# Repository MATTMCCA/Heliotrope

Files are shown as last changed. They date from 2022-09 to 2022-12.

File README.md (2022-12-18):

# Heliotrope

All hardware design was done with Altium, all 3D modeling (with the exception of available models) was done with Fusion360.

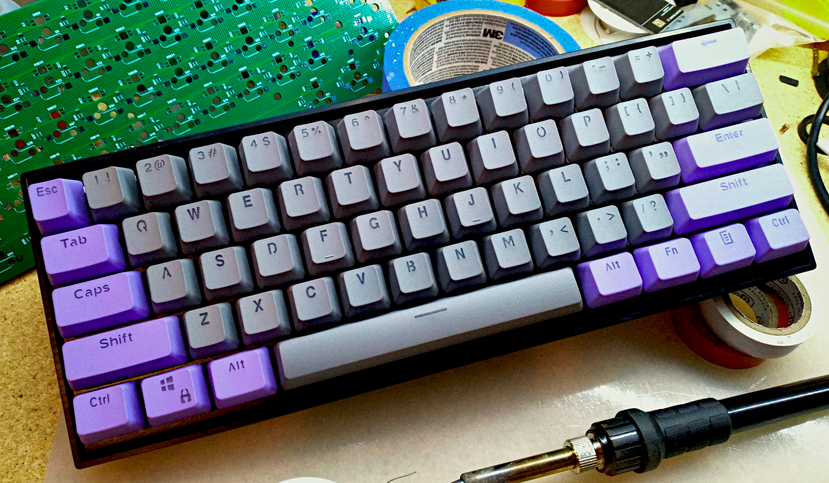
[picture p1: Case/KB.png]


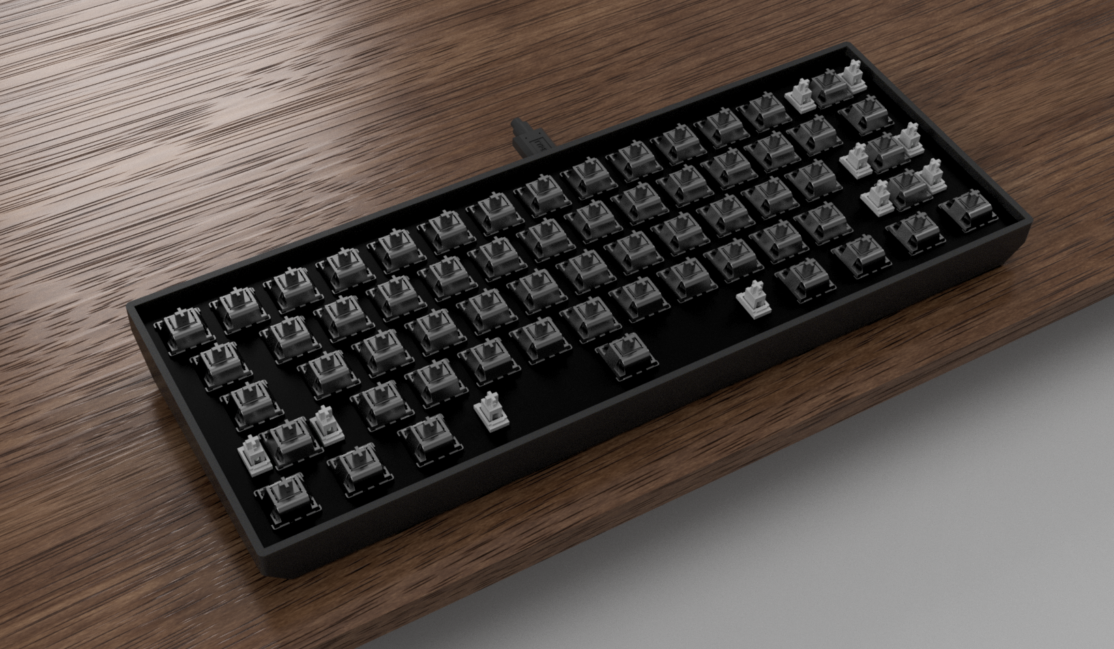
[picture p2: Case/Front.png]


MIT licensed keyboard.

"Buy Me A Coffee" (https://www.buymeacoffee.com/mccardlema3)

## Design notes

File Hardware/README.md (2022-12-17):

# View All Project Files Online

https://www.altium.com/viewer/

## Note:

Resistors R1, R2, R6, of the logic board should be changed, the **actual** current limits will be less than whats listed in the schematic.

The Keyswitch PCB still only has one via connecting VCC to all LED's. At extremely high current the via may fail. The circumference of the via is 24.7369mil, assuming 0.5oz copper plating, this should be able to handle 1.6A at a 30C rise from ambient (25C).

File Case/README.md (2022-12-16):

# Heliotrope

The Keyboard Case was milled out of ABS by [ProtoTool](https://prototool.com/). 

The KeyPlate was laser cut, formed and powered coated by [OshCut](https://www.oshcut.com/).

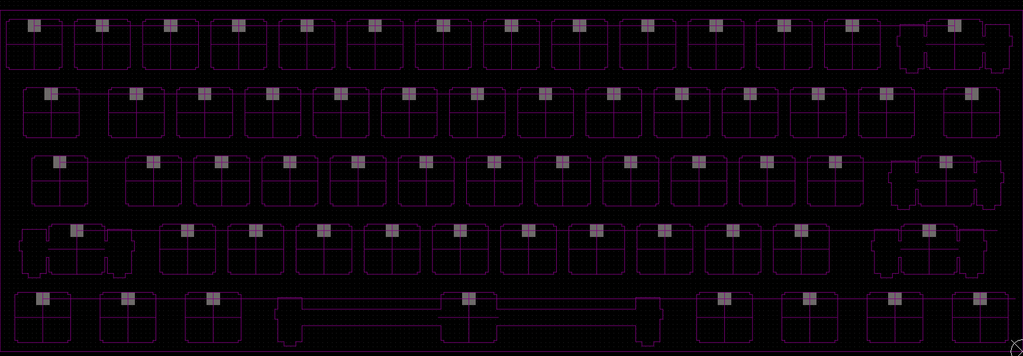
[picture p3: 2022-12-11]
Docs/src/LedPloter/ledPlot_ref_org.bmp

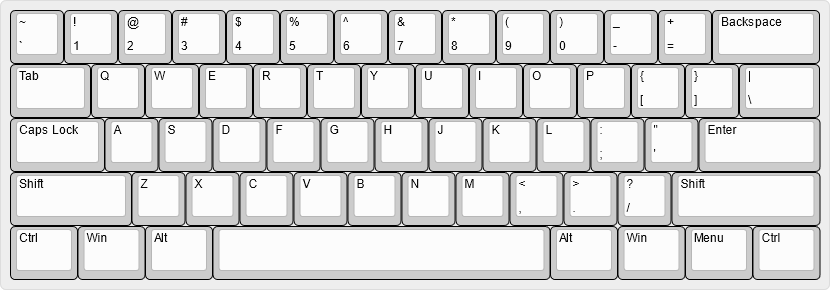
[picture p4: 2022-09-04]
Docs/src/Heliotrope_layout.png

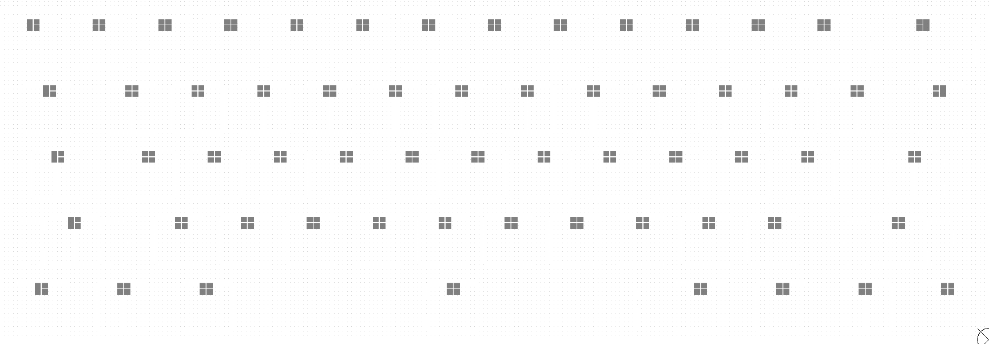
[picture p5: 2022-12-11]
Docs/src/LedPloter/ledPlot_ref.bmp

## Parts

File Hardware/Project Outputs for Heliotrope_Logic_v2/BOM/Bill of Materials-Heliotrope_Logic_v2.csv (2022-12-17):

Name | Description | Designator | Quantity | Manufacturer 1 | Manufacturer Part Number 1
53261-0271 | 1.25mm Pitch PicoBlade™ Header, Surface Mount, Right Angle, Lead-Free, 2 Circuits | P1 | 1 | Molex | 53261-0271
MIC803-26D4VC3-TR | 3-Pin Microprocessor Supervisor Circuit w/ Open-Drain Reset Output | U2 | 1 | Microchip | MIC803-26D4VC3-TR
0603L010YR | 15VDC 100mA | F1 | 1 | Littelfuse | 0603L010YR
TLV74033PDBVR | 300-mA low-dropout (LDO) regulator with foldback current limit 5-SOT-23 -40 to 125 | U3 | 1 | Texas Instruments | TLV74033PDBVR
BLM18AG601SN1D | 600 Ohms @ 100MHz 1 Ferrite Bead 0603 _1608 Metric_ 500mA 380mOhm | FL1 | 1 | Murata | BLM18AG601SN1D
CC0603JRX7R9BB104 | 0603 0.1 uF 50 V ±5 % Tolerance X7R SMT Multilayer Ceramic Capacitor | C2, C5, C6, C7, C8, C9, C10, C11, C12, C14 | 10 | Yageo | CC0603JRX7R9BB104
STM32F411CEU6 | ARM® Cortex®-M4 STM32 F4 Microcontroller IC 32-Bit 100MHz 512KB (512K x 8) FLASH 48-UFQFPN (7x7) | U1 | 1 | STMicroelectronics | STM32F411CEU6
CC0603KRX7R6BB225 | Cap Ceramic 2.2uF 10V X7R 10% SMD 0603 125C Paper T/R | C1 | 1 | Yageo | CC0603KRX7R6BB225
GRM21BR71A106KA73K | Cap Ceramic 10uF 10V X7R 10% Pad SMD 0805 125C T/R | C3, C4, C13 | 3 | Murata | GRM21BR71A106KA73K
USB4110-GF-A | Conn USB Type C RCP 16 POS 0.3mm/0.5mm Solder ST SMD 16 Terminal 1 Port T/R | J1 | 1
ECS-2520MV-080-CN-TR | ECS-2520MV Series 8MHz 2.5x2mm 3.6 V SMT HCMOS Multivolt? Crystal Oscillator | Y1 | 1 | ECS International | ECS-2520MV-080-CN-TR
RCLAMP0504FBTCT | ESD Suppressor TVS Quad Uni-Dir 30kV 6-Pin SC-70 T/R | CR1 | 1 | Semtech | RCLAMP0504FBTCT
68712014522 | Ffc / Fpc Board Connector, Zif, Surface Mount, Plug, 20, Bottom, 0.5 Mm Rohs Compliant: Yes | J2 | 1 | Wurth Electronics | 68712014522
AP22653AW6-7 | PRECISION ADJUSTABLE CURRENT-LIMITED POWER SWITCHES, -40 to 85°C pF, RoHS | U4 | 1 | Diodes | AP22653AW6-7
PTN5150AHXMP | PTN5150A Series 2.7 to 5.5 V CC Logic for USB Type-C Applications - XFQFN-12 | U5 | 1 | NXP Semiconductors | PTN5150AHXMP
RMCF0603JT1K00 | Res Thick Film 0603 1K Ohm 5% 1/10W ±200ppm/°C Molded SMD Paper T/R | R5 | 1 | Stackpole Electronics | RMCF0603JT1K00
RMCF0603JT10K0 | Res Thick Film 0603 10K Ohm 5% 1/10W ±100ppm/°C Molded SMD SMD Paper T/R | R4, R7 | 2 | Stackpole Electronics | RMCF0603JT10K0
RMCF0603FT33K0 | Res Thick Film 0603 33K Ohm 1% 0.1W(1/10W) ±100ppm/C Pad SMD Automotive T/R | R2 | 1 | Stackpole Electronics | RMCF0603FT33K0
RMCF0603FT62K0 | Res Thick Film 0603 62K Ohm 1% 1/10W ±100ppm/°C Molded SMD SMD Paper T/R | R1 | 1 | Stackpole Electronics | RMCF0603FT62K0
RMCF0603JT100K | Res Thick Film 0603 100K Ohm 5% 1/10W ±200ppm/°C Molded SMD Paper T/R | R3 | 1 | Stackpole Electronics | RMCF0603JT100K
RMCF0603FT102K | Res Thick Film 0603 102K Ohm 1% 1/10W ±100ppm/°C Molded SMD SMD Paper T/R | R6 | 1 | Stackpole Electronics | RMCF0603FT102K
PTS526SK15SMTR2LFS | Switch Tactile N.O. SPST Round Button Gull Wing 0.05A 12VDC 200000Cycles 2.55N SMD T/R | SW1 | 1 | ITT C&K | PTS526SK15SMTR2LFS

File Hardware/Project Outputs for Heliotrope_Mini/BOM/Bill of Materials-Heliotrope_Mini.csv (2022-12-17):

Name | Description | Designator | Quantity | Manufacturer 1 | Manufacturer Part Number 1
CC0603JRX7R9BB104 | 0603 0.1 uF 50 V ±5 % Tolerance X7R SMT Multilayer Ceramic Capacitor | C1, C2, C3, C4, C5, C6, C7, C8, C9, C10, C11, C12, C13, C14, C15, C16, C17, C18, C19, C20, C21, C22, C23, C24, C25, C26, C27, C28, C29, C30, C31, C32, C33, C34, C35, C36, C37, C38, C39, C40, C41, C42, C43, C44, C45, C46, C47, C48, C49, C50, C51, C52, C53, C54, C55, C56, C57, C58, C59, C60, C61 | 61 | Yageo | CC0603JRX7R9BB104
RB520S30T5G | RB520S30T5G - 30 V 200 mA Surface Mount Schottky Diode - SOD-523 | D1, D2, D3, D4, D5, D6, D7, D8, D9, D10, D11, D12, D13, D14, D15, D16, D17, D18, D19, D20, D21, D22, D23, D24, D25, D26, D27, D28, D29, D30, D31, D32, D33, D34, D35, D36, D37, D38, D39, D40, D41, D42, D43, D44, D45, D46, D47, D48, D49, D50, D51, D52, D53, D54, D55, D56, D57, D58, D59, D60, D61 | 61 | ON Semiconductor | RB520S30T5G
68712014522 | Ffc / Fpc Board Connector, Zif, Surface Mount, Plug, 20, Bottom, 0.5 Mm Rohs Compliant: Yes | J1 | 1 | Wurth Electronics | 68712014522
53261-0271 | 1.25mm Pitch PicoBlade™ Header, Surface Mount, Right Angle, Lead-Free, 2 Circuits | P1 | 1 | Molex | 53261-0271
SK6812MINI-E | SK6812MINI-E | RGB1, RGB2, RGB3, RGB4, RGB5, RGB6, RGB7, RGB8, RGB9, RGB10, RGB11, RGB12, RGB13, RGB14, RGB15, RGB16, RGB17, RGB18, RGB19, RGB20, RGB21, RGB22, RGB23, RGB24, RGB25, RGB26, RGB27, RGB28, RGB29, RGB30, RGB31, RGB32, RGB33, RGB34, RGB35, RGB36, RGB37, RGB38, RGB39, RGB40, RGB41, RGB42, RGB43, RGB44, RGB45, RGB46, RGB47, RGB48, RGB49, RGB50, RGB51, RGB52, RGB53, RGB54, RGB55, RGB56, RGB57, RGB58, RGB59, RGB60, RGB61 | 61 | DONGGUAN OCCIDENTAL OPTOELECTRONICS | SK6812MINI-E
1U | Keyswitch 1U Cherry MX | S1, S2, S3, S4, S5, S6, S7, S8, S9, S10, S11, S12, S13, S15, S16, S17, S18, S19, S20, S21, S22, S23, S24, S25, S26, S27, S28, S29, S30, S31, S32, S33, S34, S35, S36, S37, S38, S39, S40, S43, S44, S45, S46, S47, S48, S49, S50, S51, S52, S54, S55, S56, S58, S59, S60, S61 | 56
2U | Keyswitch 2U Cherry MX | S14, S41, S42, S53 | 4
6.25U | Keyswitch 6.25U Cherry MX | S57 | 1

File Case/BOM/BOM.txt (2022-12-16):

Digikey
-----------------------------------------
x7   2254-HM20X157C-ND

McMaster
-----------------------------------------
x2    94017A102
x5    94017a108

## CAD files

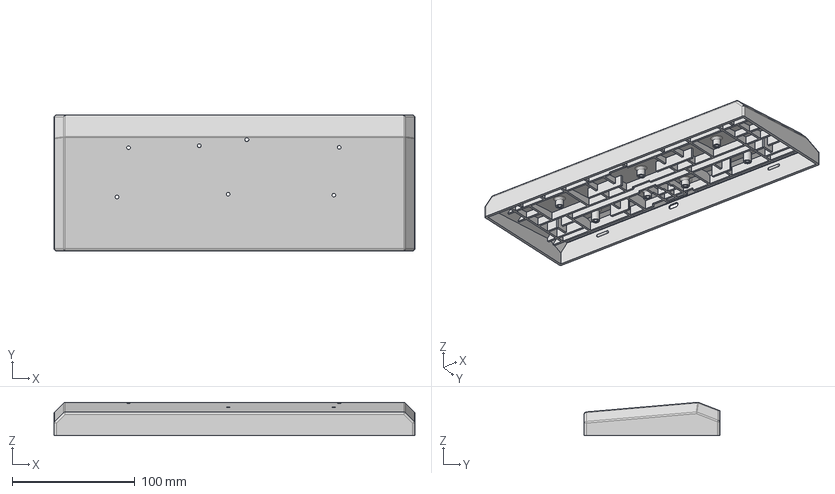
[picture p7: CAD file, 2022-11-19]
Case/OSHCut/Case_Fab.step
293.8 x 110.4 x 27.2 mm

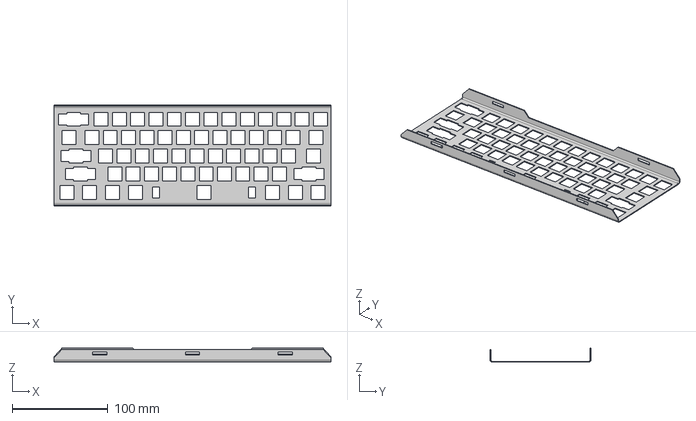
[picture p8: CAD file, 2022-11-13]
Case/ProtoTools/Plate_Fab.step
288.8 x 105.4 x 15.0 mm

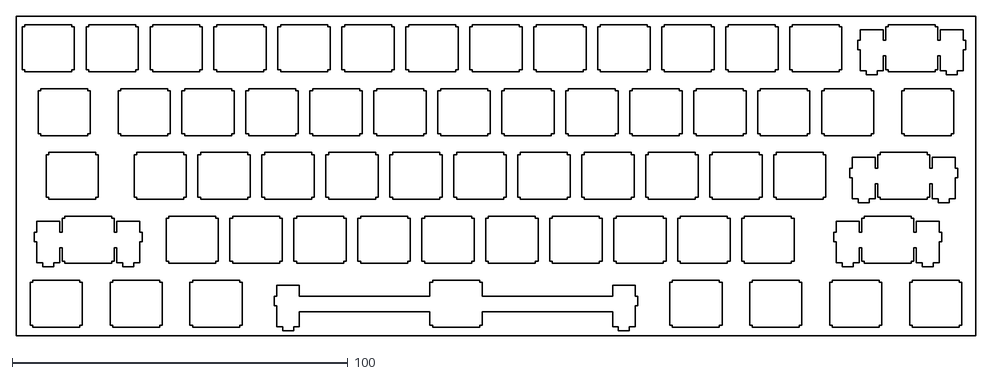
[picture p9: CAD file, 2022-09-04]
Docs/src/Heliotrope_switch.dxf
285.7 x 95.2

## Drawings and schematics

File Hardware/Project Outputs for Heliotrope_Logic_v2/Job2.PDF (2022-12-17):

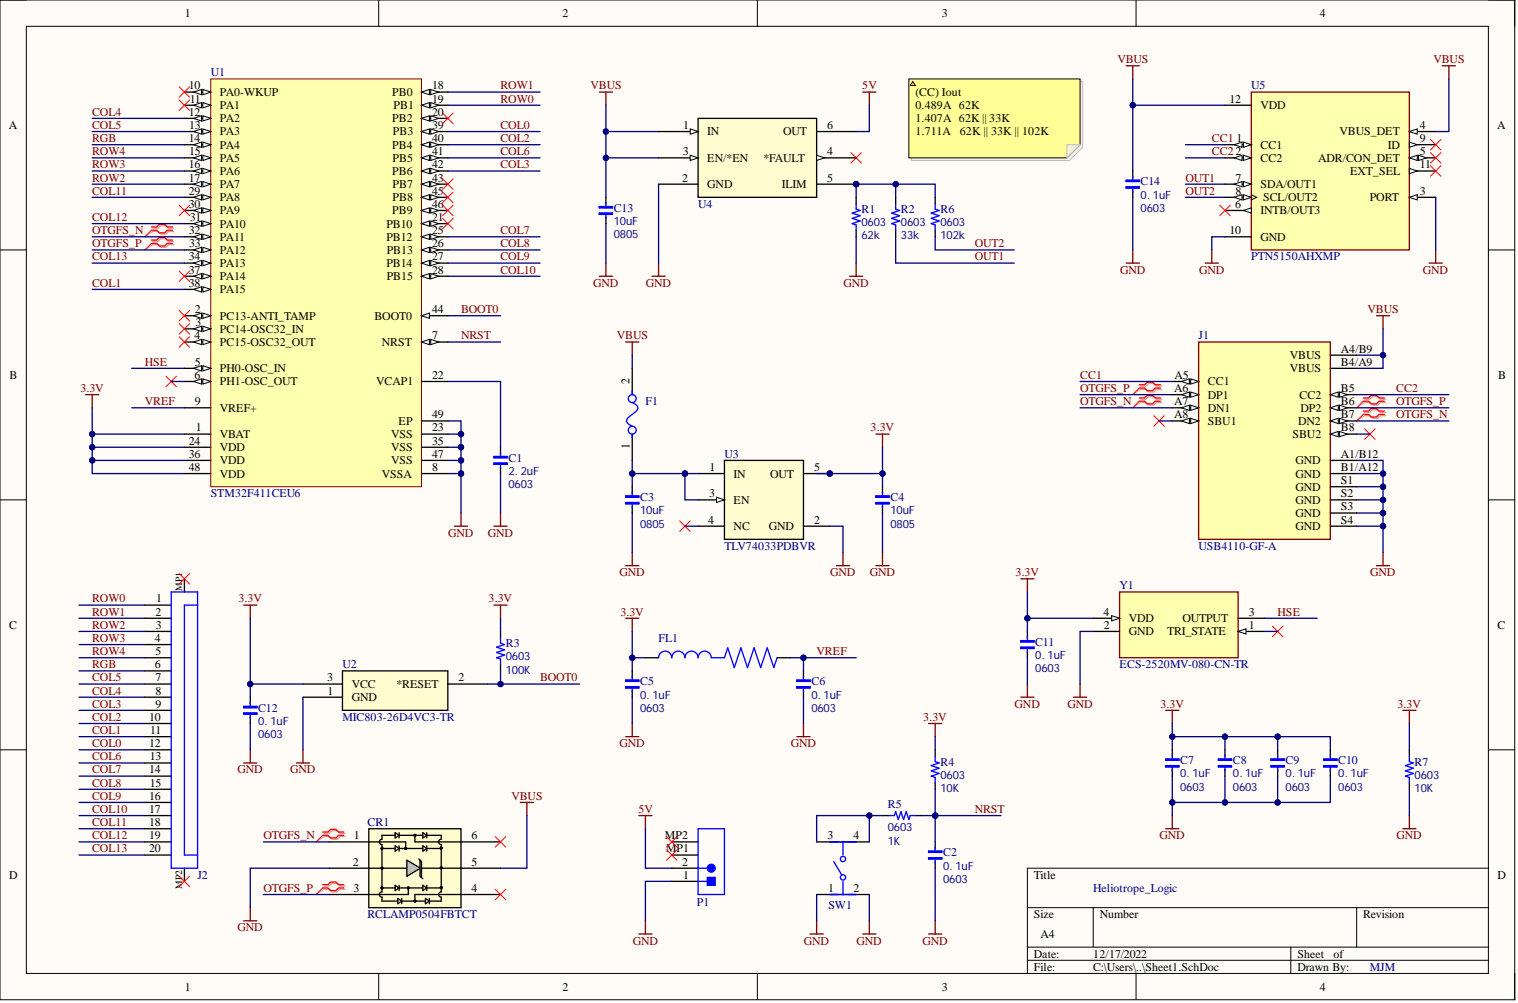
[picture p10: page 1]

2 4 | | 3 5
3 6 | | 4 7

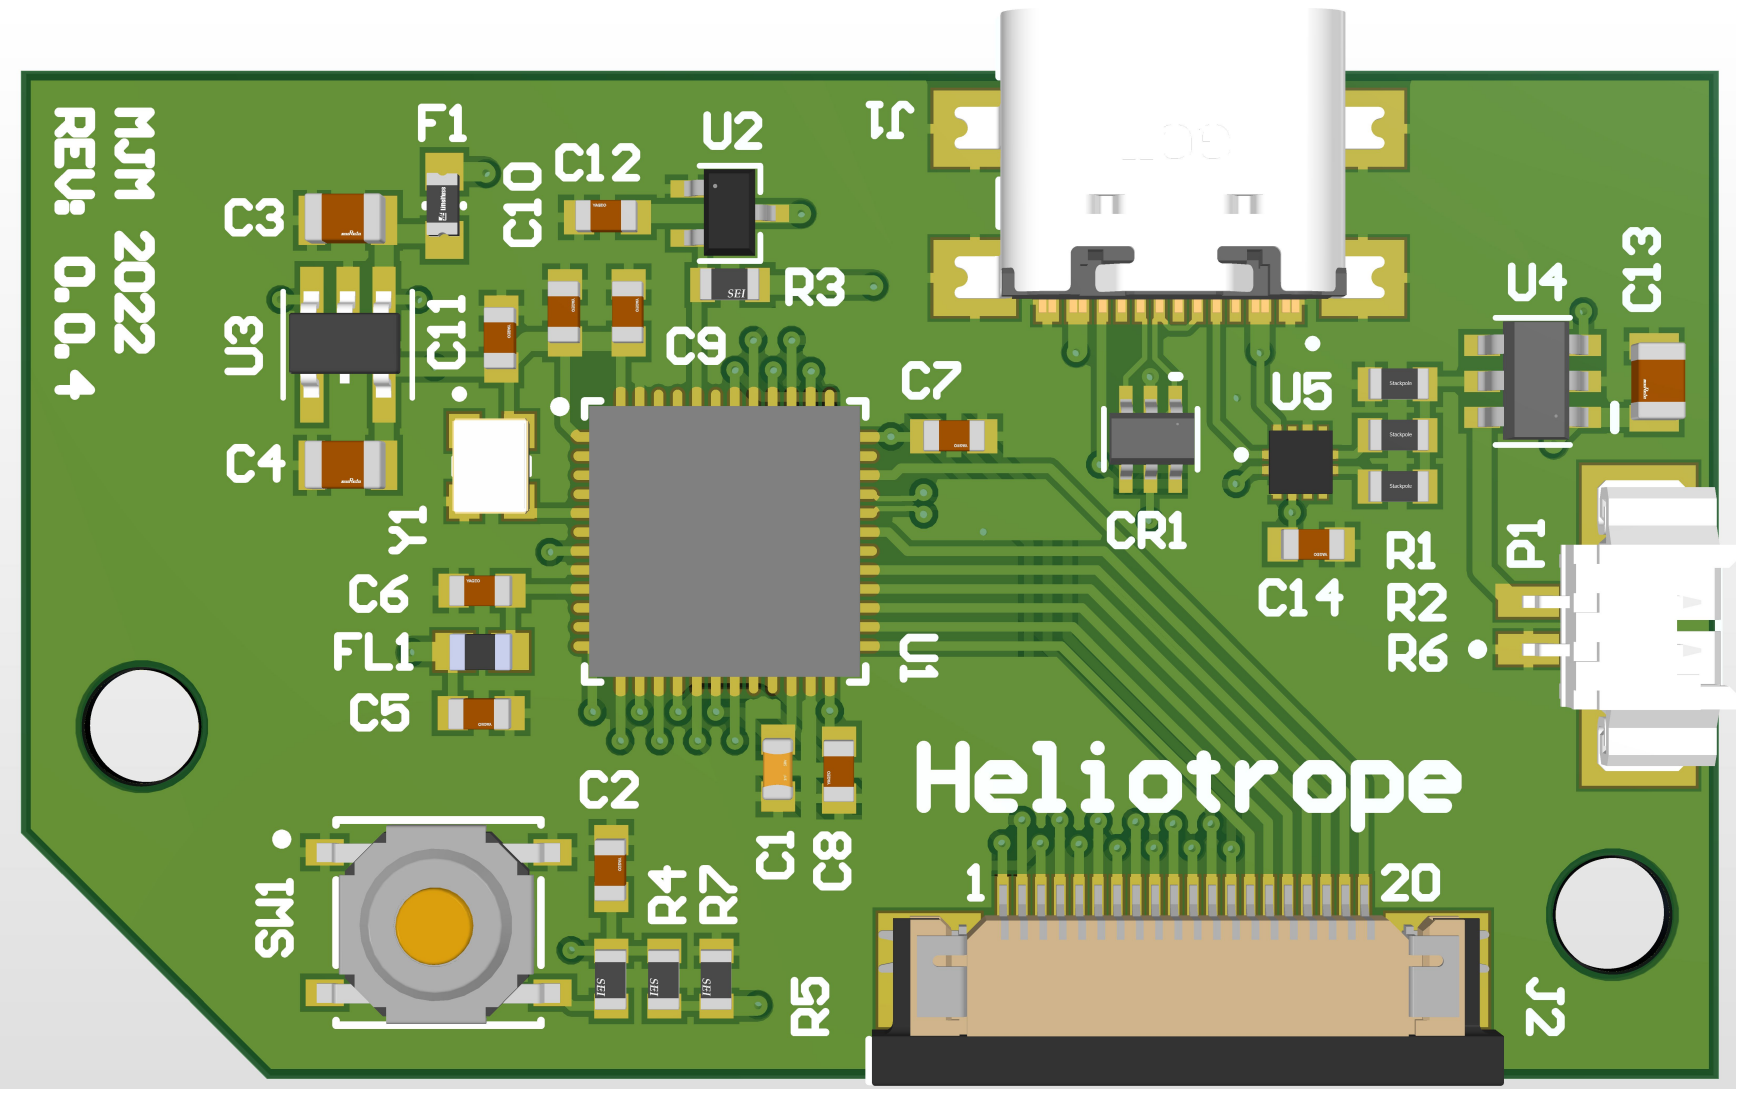
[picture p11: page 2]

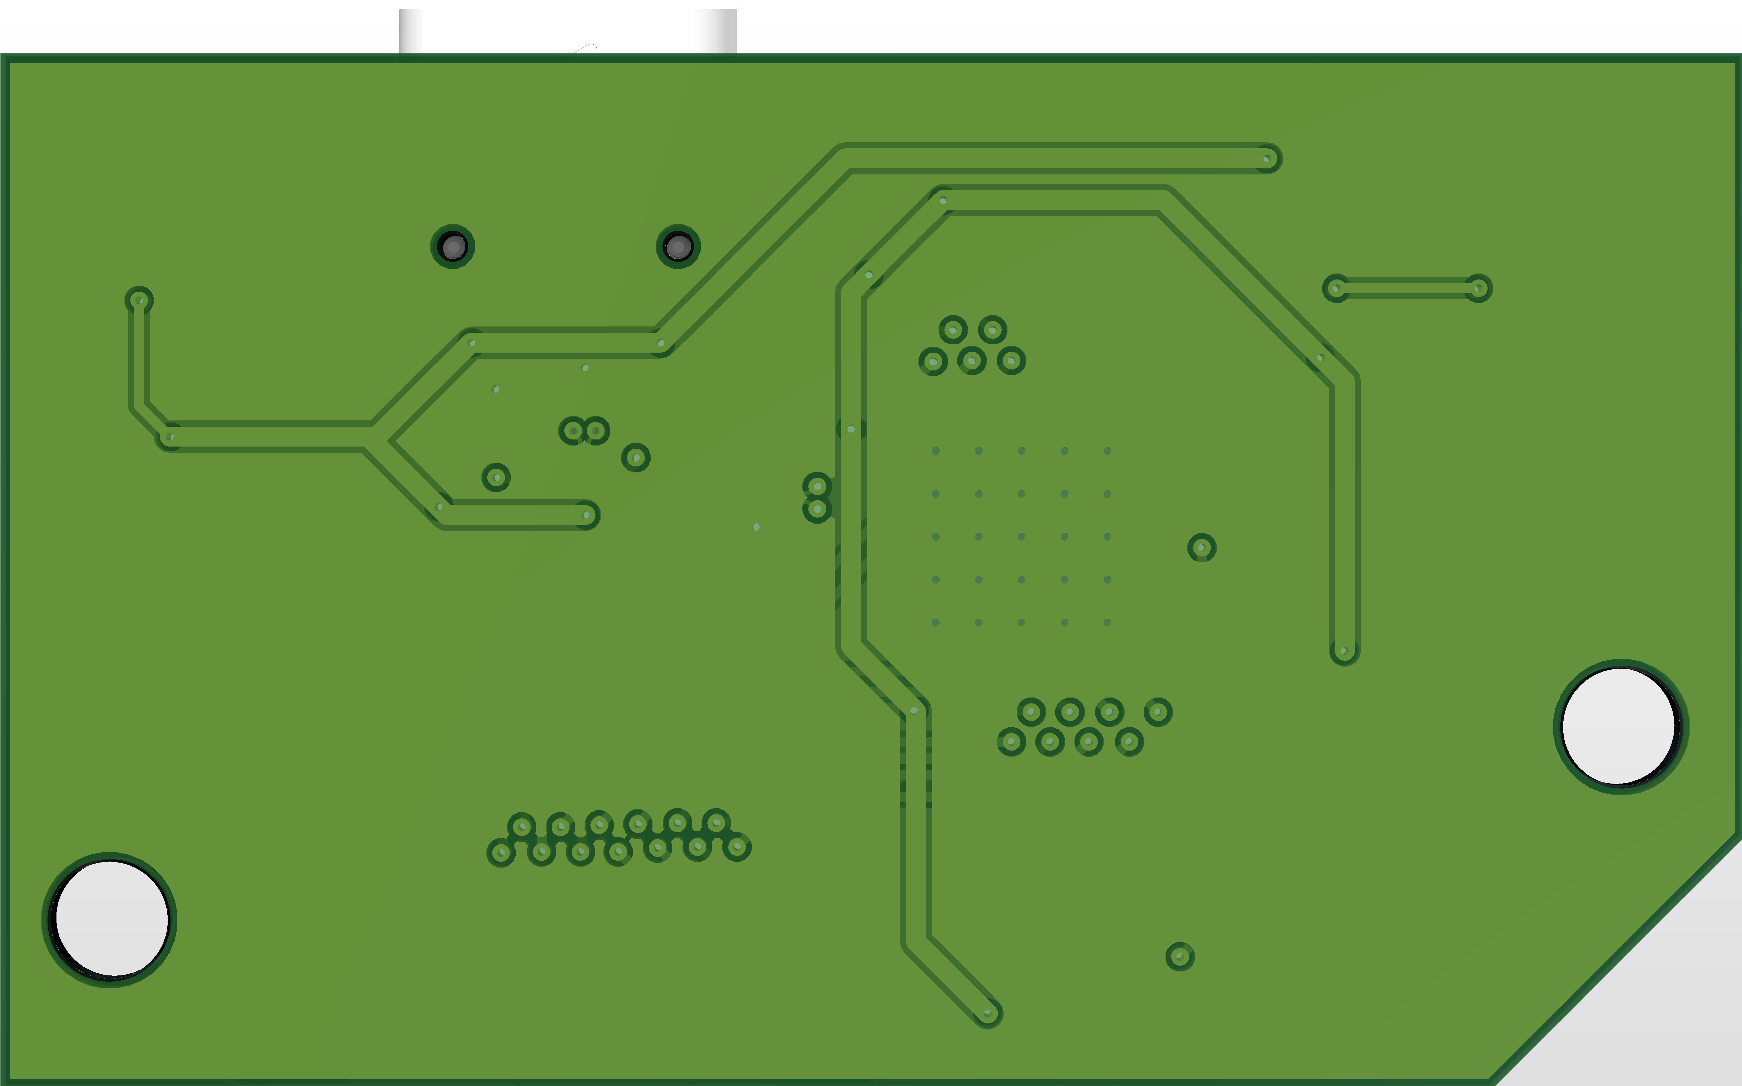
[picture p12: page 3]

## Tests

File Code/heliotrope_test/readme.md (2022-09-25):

# heliotrope_test

heliotrope_test

*A short description of the keyboard/project*

* Keyboard Maintainer: [MJM](https://github.com/MATTMCCA)
* Hardware Supported: *The PCBs, controllers supported*
* Hardware Availability: *Links to where you can find this hardware*

Make example for this keyboard (after setting up your build environment):

    make heliotrope_test:default

Flashing example for this keyboard:

    make heliotrope_test:default:flash

See the [build environment setup](https://docs.qmk.fm/#/getting_started_build_tools) and the [make instructions](https://docs.qmk.fm/#/getting_started_make_guide) for more information. Brand new to QMK? Start with our [Complete Newbs Guide](https://docs.qmk.fm/#/newbs).

## Bootloader

Enter the bootloader in 3 ways:

* **Bootmagic reset**: Hold down the key at (0,0) in the matrix (usually the top left key or Escape) and plug in the keyboard
* **Physical reset button**: Briefly press the button on the back of the PCB - some may have pads you must short instead
* **Keycode in layout**: Press the key mapped to `QK_BOOT` if it is available

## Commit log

2022-09-04 project outputs
    [Bill of Materials-Heliotrope_Logic.xlsx, Bill of Materials-Heliotrope_Mini.xlsx, Breakout.SchDoc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]
2022-09-04 update
    changed led count from 64 to 61, idk where I got 64 at, must have had hex on the brain.
2022-09-04 edit
    added sanity notes.
    [Bill of Materials-Heliotrope_Logic.xlsx, Bill of Materials-Heliotrope_Mini.xlsx, Breakout.SchDoc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]
2022-09-05 shrank boards
    In leu of cheap resin printing, I changed the board design to better fit a resin case.
    [Bill of Materials-Heliotrope_Logic.xlsx, Bill of Materials-Heliotrope_Mini.xlsx, Breakout.SchDoc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]
2022-09-05 case test
    [Component278 v3.step]
2022-09-05 Create Component278 v3.stl
    [Component278 v3.stl]
2022-09-06 logic board change, flipped orientation
    Added note about press in threads.
    Flipped power connector (polarity might be wrong, but keyed) .
    [Bill of Materials-Heliotrope_Logic.xlsx, Bill of Materials-Heliotrope_Mini.xlsx, Breakout.SchDoc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]
2022-09-06 fixed board renders
2022-09-07 case test
    prelim layout and sanity check.
    #NoviceAtFusion360
    [Component278 v3.step, Component278 v3.stl]
2022-09-10 case update
2022-09-10 added case hardware docs
2022-09-10 case rev
    added support structures to case material. (hope its enough)
2022-09-10 added fab files and render
    [BOT_MID.step, PLATE.step, TOP.step]
2022-09-10 Update BOM.txt
    I guess I can't count....
2022-09-10 Update BOM.txt
    ?
2022-09-11 fixed case
    off to fab... again...
    [BOT_MID.step, BOT_MID_STL.stl, PLATE.step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]
2022-09-11 board update
    [Bill of Materials-Heliotrope_Logic.xlsx, Bill of Materials-Heliotrope_Mini.xlsx, Breakout.SchDoc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]
2022-09-11 Gerber's added
2022-09-24 switch plate test fit
2022-09-26 fab issue
    The fab said the top frame would warp, this is my attempt at fixing it for manufacturing.
    [TOP_v2.step, TOP_v2_STL.stl]
2022-09-30 Create 013.jpeg
    soldered 90% of the matrix PCB, almost ready for functional testing. TODO: the connectors. plus I forgot to order 2pos picoblade connectors lol nerp!
2022-10-02 fixed RGB Leds
    updated board design, sent design to fab.
    [Bill of Materials-Heliotrope_Mini.xlsx, Breakout.SchDoc, MATRIX.SchDoc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]
2022-10-06 updated files for fab
    these Gerber's made it to production. the RGB cutout was still wrong, this is the newest rev.
    [Bill of Materials-Heliotrope_Mini.xlsx, Breakout.SchDoc, MATRIX.SchDoc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]
2022-10-08 Create STM32 BL-RST.png
    Random Idea for auto bootload/reset, stm32.
    on power up, jump to flash, if in flash after 400ms and mcu gets a reset, jump to bootloader.
    Removing and applying power should let the stm jump to user flash (plug and unplug).
    so the idea is, the reset button functions as a BL jump after 400ms of applied power. But a full power cycle will always let the stm jump to flash.
    c1 will charge slow but discharge fast. unity gain buffer will "buffer" the cap voltage? and the Schmitt trigger wont trigger untill the cap hits 4v.
    and no, the stm32 is not a 5v animal, this is a concept schematic.
2022-10-08 Create STM32 BL-RST_BETTER.png
    Or I save myself the trouble and just use a dedicated IC lol!
2022-10-15 added another logic board
    [Bill of Materials-Heliotrope_Logic_v2.xlsx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]
2022-10-21 heliotrope purple update
    The deadliest purple of them all!
    [PLATE.dwg]
2022-10-30 project update
    sent my logic files to fab, parts are on order.
    [Bill of Materials-Heliotrope_Logic.xlsx, Bill of Materials-Heliotrope_Logic_v2.xlsx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]
2022-10-30 added PowerSafe
    passive current limiting for testing.
    [Bill of Materials-PowerSafe.xlsx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]
2022-11-02 housekeeping + rev plan
    project update, nuked old files, added new files.
    [Bill of Materials-PowerSafe.xlsx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]
2022-11-05 update
    usb power spec revision.
    [Bill of Materials-Heliotrope_Logic_v2.xlsx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]
2022-11-05 forgot to save
    new files
    [Bill of Materials-Heliotrope_Logic_v2.xlsx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]
2022-11-05 changed R value from 30k to 33k
    changed r value to lower supply current.
    [Bill of Materials-Heliotrope_Logic_v2.xlsx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]
2022-11-05 fixed another R value and math
    [Bill of Materials-Heliotrope_Logic_v2.xlsx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]
2022-11-05 added running bomb
    my last two orders for ref.
    [78486782.csv, 78589065.csv]
2022-11-06 csv bom
    [78486782.csv, 78589065.csv, consolidated.csv]
2022-11-06 changed power trace from 10mill to 20mill
    [Bill of Materials-Heliotrope_Logic_v2.xlsx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]
2022-11-06 updated fab files from altium
    created manufacturing zip
    [Bill of Materials-Heliotrope_Mini.xlsx, Breakout.SchDoc, MATRIX.SchDoc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]
2022-11-06 changed silk screen
    silk overlapped pad, so I removed it.
    [Bill of Materials-Heliotrope_Logic_v2.xlsx, Hardware.csv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]
2022-11-11 new pre-heater
    added pic
2022-11-13 testing case idea
    playing with cad
    [Case_test.step, Fit_test.step, Plate_test.step]
2022-11-19 hw
    added pick and place files
    [Pick Place for PCB1.csv]
2022-11-19 Official QMK Support for Logic Board
    Official QMK Support for Logic Board, Will test soon!
2022-11-19 house keeping
    [Case_Fab.step, Case_test.step, Fit_test.step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]
2022-11-24 Update README.md
    Found another board mistake.
2022-11-25 PCB FIX
    Swapped I_set Resistors.
    Change load switch part number.
    Fused logic supply so I can change led brightness after the load switch goes into failure mode.
    Redid the layout completely, I moved the button to the other side of the board.
    Added 10K bleed resistor on the 3.3v rail.
    Fixed FFC labels in the schematic to match up with QMK better.
    REMOVED PA9 AS AN INPUT!!!!!
    I still need to do some other things before sending it off to fab.
    [Bill of Materials-Heliotrope_Logic_v2.xlsx, Heliotrope Logic Board.csv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]
2022-11-26 board change
    [Bill of Materials-Heliotrope_Logic_v2.xlsx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]
2022-12-04 update
    changed a few part numbers and re-exported the project.
    [Bill of Materials-Heliotrope_Logic_v2.csv, Bill of Materials-Heliotrope_Logic_v2.xlsx, Bill of Materials-Heliotrope_Mini.csv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]
2022-12-11 matrix solution
    Learning about QMK's LED matrix implementation.
    Code generates x,y for bmp with (224,64) constraints.
    On hardware everything looks perfect after fixing my matrix in json.
2022-12-16 house keeping
    cleaned up repo.
    [BOT_MID.step, BOT_MID_STL.stl, PLATE.dwg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]
2022-12-17 update
    Redid the key switch PCB, I didn't like the layout of rev 2.
    Also updated 3d model to reflect change.
    [Bill of Materials-Heliotrope_Mini.csv, Breakout.SchDoc, MATRIX.SchDoc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]
2022-12-17 update
    fixed 2 missing tracks, and fixed silkscreen.
    [Breakout.SchDoc, MATRIX.SchDoc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]
2022-12-17 update
    Fixed Gerbers, ready for fab.
    [Breakout.SchDoc, MATRIX.SchDoc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]
2022-12-17 update
    re-exported logic board.
    Sending everything to fab, 5x logic pcb & 5x keyswitch pcb.
    [Bill of Materials-Heliotrope_Logic_v2.csv, PCB1.PcbDoc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]
2022-12-17 Update README.md
    resistor note.
